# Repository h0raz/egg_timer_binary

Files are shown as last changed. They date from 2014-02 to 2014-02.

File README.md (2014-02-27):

egg_timer_binary
===================

My image

This is/will be a egg timer with a battery powered binary display

It shows either the minutes in 6 bits and the seconds or if time is greater than one hour the hour and the minutes and the seconds ticking

If the timer reaches zero it will beep until the rotary encoder is pressed

While the timer is not active you can change the timer by turning the encoder. Start/Pause, Reset is a Push on the encoder

If the seconds are not zero(eg you paused it) and you change the time the seconds will be set to 0

I set the OSCCAL so the drift is minimal and I don't need any crystal

As you can asume this project is still in development

The firmware is functional and finished for now but the layout needs some tweaking and I'm currently searching for a case which has the right size

> **Todo/Bugs:**
> 
> - Power down mode after a timeout
> - generalize Pin/Port settings
> - translate comments etc.
> - sound is a bit aweful
> - PCB desing
> - find case

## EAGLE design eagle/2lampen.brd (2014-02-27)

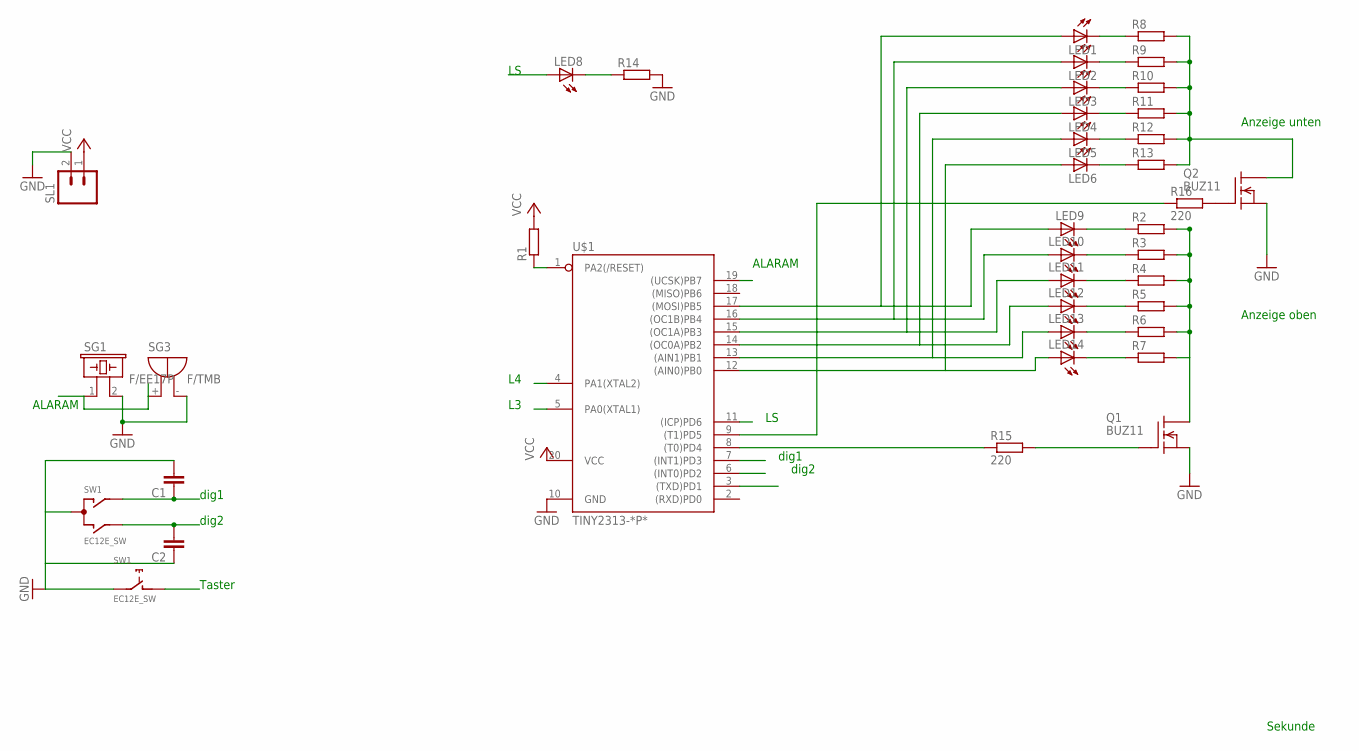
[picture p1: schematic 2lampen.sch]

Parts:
C1, C2: C-EU025-025X050; C025-025X050
LED1, LED2, LED3, LED4, LED5, LED6, LED9, LED10, LED11, LED12, LED13, LED14: LED5MM
LED8: LED3MM
Q1, Q2: BUZ11; TO220
R1, R13: R-EU_0204/7; 0204/7
R2, R3, R4, R5, R6, R7, R8, R9, R10, R11, R12, R14: R-EU_0204/2V; 0204V
R15, R16: 220; 0204V
SG1: F/EE17P
SG3: F/TMB
SL1: M02; 02P
SW1: EC12E_SW; ALPS_EC12E_SW
U$1: TINY2313-*P*; DIL20

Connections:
ALARM: SG1.1, SG3.+, U$1.19 ((UCSK)PB7)
DIG1: C1.1, SW1.A, U$1.7 ((INT1)PD3)
DIG2: C2.2, SW1.B, U$1.6 ((INT0)PD2)
GND: C1.2, C2.1, Q1.3 (S), Q2.3 (S), R14.2, SG1.2, SG3.-, SL1.2, SW1.C, SW1.E (2), U$1.10 (GND)
L1: LED1.A, LED9.A, U$1.17 ((MOSI)PB5)
L2: LED2.A, LED10.A, U$1.16 ((OC1B)PB4)
L3: LED3.A, LED11.A, U$1.5 (PA0(XTAL1)), U$1.15 ((OC1A)PB3)
L4: LED4.A, LED12.A, U$1.4 (PA1(XTAL2)), U$1.14 ((OC0A)PB2)
L5: LED5.A, LED13.A, U$1.13 ((AIN1)PB1)
L6: LED6.A, LED14.A, U$1.12 ((AIN0)PB0)
LS: LED8.A, U$1.11 ((ICP)PD6)
unnamed: LED6.K (C), R13.1
unnamed: LED5.K (C), R12.1
unnamed: LED4.K (C), R11.1
unnamed: LED3.K (C), R10.1
unnamed: Q1.2 (D), R2.2, R3.2, R4.2, R5.2, R6.2, R7.2
unnamed: LED2.K (C), R9.1
unnamed: LED1.K (C), R8.1
unnamed: LED8.K (C), R14.1
unnamed: LED9.K (C), R2.1
unnamed: LED10.K (C), R3.1
unnamed: LED11.K (C), R4.1
unnamed: LED12.K (C), R5.1
unnamed: LED13.K (C), R6.1
unnamed: LED14.K (C), R7.1
unnamed: Q2.2 (D), R8.2, R9.2, R10.2, R11.2, R12.2, R13.2
unnamed: Q1.1 (G), R15.2
unnamed: Q2.1 (G), R16.2
unnamed: R16.1, U$1.9 ((T1)PD5)
unnamed: R15.1, U$1.8 ((T0)PD4)
RESET: R1.1, U$1.1 (PA2(/RESET))
TAST: SW1.D (1)
VCC: R1.2, SL1.1, U$1.20 (VCC)

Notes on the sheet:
ALARAM
dig1
dig2
Taster
Anzeige oben
Anzeige unten
Sekunde

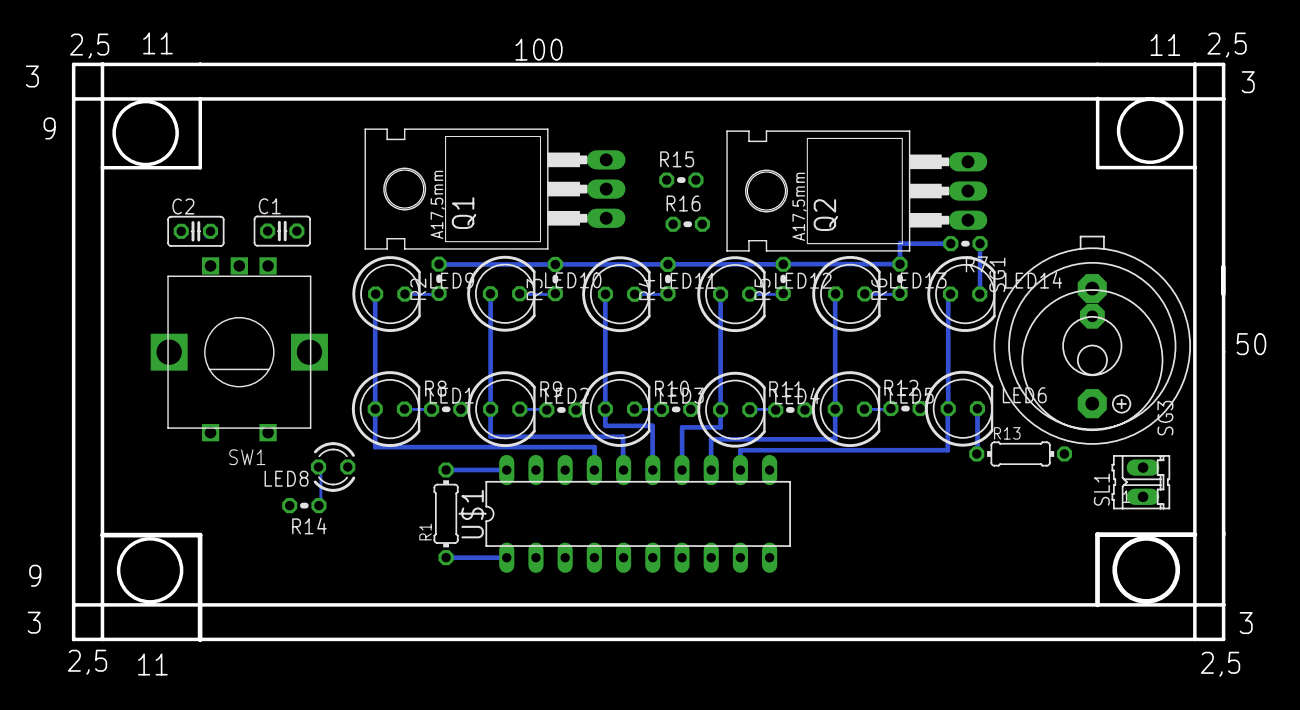
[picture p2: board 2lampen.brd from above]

Board: 2 copper layers, 100.0 x 50.0 mm, 38 parts (0 on the bottom side), 32 nets.

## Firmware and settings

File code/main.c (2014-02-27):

#include "main.h"

time_t *time = &gtime;

uint8_t timeshow(uint8_t ltime) {
    uint8_t show = 0;
    for(uint8_t i = 0; i <= 6; i++) {
        if (ltime & (1 << (5 - i))) {
            show |= (1 << i);
        }
    }
    return show;
}
void Zrpos() {
    if (time->s == 60) {
        time->s = 0;
        time->m++;
    }
    if (time->m == 60) {
        time->m = 0;
        time->h++;
    }
    if (time->h == 24) {
        time->h = 0;
    }
}

void Zrneg() {
    if (time->s == 255) {
        time->s = 59;
        time->m--;
    }
    if (time->m == 255) {
        time->m = 59;
        if (time->h > 0) {
            time->h--;
        }
    }
    if (time->h == 255) {
        time->h = 23;
        time->m = 59;
    }
}

void init(void) {
    //AUS/Eingänge festlegen
    TIMELEDDDR |= TIMELEDS;
    TIMESLEDDDR |= SLED;
    TIMELEDGNDDDR |= TIMELED1GND | TIMELED2GND;
    TASTERDDR &= ~(TASTER | DREH1 | DREH2);
    TIMELEDGNDP |= TIMELED1GND | TIMELED2GND;
    ALARMDDR|= ALARM1 | ALARM2;
    TASTERP |= DREH1 | DREH2 | TASTER;  //Taster auf aktive Low setzen

    OCR1AH = 244;       //Timer1_ Comp
    OCR1AL = 35;            //Timer1_ Comp  auf 62499 gestellt->Interrupt bei 62500; 8000000/62500/sekszori(128) ergibt 1s
    TCCR1B |= (1<<WGM12) | (1<<CS10);       //Timer1 auf CTC setzen und Timer1 prescaler setzten
    TCCR0B |= (1<<CS00);            //precaler für Timer0 auf /1 setzten
    TIMSK |= (1<<OCIE1A) | (1<<TOIE0);      //  Timer1 Init(Compare Match mode) und Timer0 Overflow Interrupt
    GIMSK |= (1<<PCIE);     //Global Interrupt Flag für PCINT setzen
    //PCMSK |= (1<<PCINT0) | (1<<PCINT1) | (1<<PCINT2);
    time->s = 0;        //Startzeit nach Init festlegen
    time->m = 5;
    time->h = 0;
    sekz = SEKZORI; //= (uint8_t)((1000000/1)/(OCR1H*256+OCR1L));
}

void statechange(uint8_t state) {
    if (state == AUS) {
        status = AUS;
        //leds off?
    }
    else if (state == CHO) {
        if (status == ALARM) {
            time->s = 0;
            time->m = 5;
            time->h = 0;
            sekz = SEKZORI;
            ALARMP &= ~(ALARM1|ALARM2);
        }
        status = CHO;
        TIMESLEDPORT &= ~SLED;
    }
    else if (state == RUN) {
        status = RUN;
    }
    else if (state == ALARM) {
        status = ALARM;
        sekz = SEKZORI/2;
        ALARMP |= ALARM1;
        ALARMP &= ~ALARM2;
        TIMESLEDPORT &= ~SLED;
    }
}

ISR (TIMER1_COMPA_vect) {
    comp();
}

void comp() {
    /*if (buttonstate == NLL) {
        count3 = (++count3) % (6);
        if (count3 == 0) {
            buttonstate = NONE;
            if ((PINB & TASTERP) == 0x00) {
                switch(status) {
                    case CHO: statechange(RUN); break;
                    case RUN: statechange(CHO); break;
                    case ALARM: statechange(CHO); break;
                }
            }
        }
    }*/
    count2 = (++count2) % sekz;
    if (status == ALARM && (count2 == ALARMDUTY)) {
        alarmstate = 1;
    }
    else if (count2 == 0) {
        alarmstate = 0;
    }

    if (status == RUN && count2 == 0) {
        time->s--;
        if (time->s == 0 && time->m == 0 && time->h == 0) {
            statechange(ALARM);
        }
        else {
            Zrneg();
        }
        if (time->h>0) {
            TIMESLEDPORT |=SLED;
        }
        else{
            TIMESLEDPORT &=~SLED;
        }
    }
    if (status==RUN && (count2==(sekz/2))) {
        TIMESLEDPORT &=~SLED;
    }

}

void buttoncheck(void) {
    uint8_t buttons = PINB & 0x07;
    if (button_state != BUT_LONG && button_state != BUT_SHORT) {
        if ((buttons & TASTER) != 0x04) {
            if (button_state != BUT_HOLD) {
                button_state = BUT_PRESSED;
                button_count++;
                if (button_count >= 800) {
                    button_state = BUT_LONG;
                }
            }
        }
        else{
            if (button_state == BUT_PRESSED && button_count >= 100) {
                button_state = BUT_SHORT;
            }
            else{
                button_state = BUT_NONE;
            }
        }
    }
    uint8_t zust = (buttons & 0x03);
    if (zust != zust_state) {
        if (zust == zust_new_state) {
            zust_count++;
        }
        else{
            zust_count = 0;
            zust_new_state = zust;
        }
        if (zust_count == 5) {
            zust_state=zust_new_state;

            if ((zust_state == DREH2) && dstate != 22) {
                dstate = 11;
            }
            else if ( zust_state == DREH1 && dstate != 12) {
                dstate = 21;
            }
            else if (dstate == 12 && zust_state == DREH1) {
                dstate = 13;
            }
            else if (dstate == 21 && zust_state == 0) {
                dstate = 22;
            }
            else if (dstate == 23 && zust_state == DREH12) {
                dstate = 24;
            }
            else if (dstate == 11 && zust_state == 0) {
                dstate = 12;
            }
            else if (dstate == 13 && zust_state == DREH12) {
                dstate = 14;
            }

            else if (dstate == 22 && zust_state == DREH2) {
                dstate = 23;
            }
            else{
                dstate=0;
            }
        }
    }
}


ISR(TIMER0_OVF_vect) {
    count++;
    if (count % 8 == 0) {
        buttoncheck();
    }
    if (count == 0)
        counterflag = NLL;
    if (count == SPWM_V)
        counterflag = L2;
    else if (count == 2 * SPWM_V - 1)
        counterflag = RES;
    if (count % ALARMFREQUENCY == 0 && alarmstate == 1) {
        ALARMP ^= ALARM1;
        ALARMP ^= ALARM2;
    }
}

int main(void) {
    init();
    statechange(CHO);
    sei();
    while(1)
    {

        if (button_state == BUT_LONG || button_state == BUT_SHORT) {
            button_state = BUT_HOLD;//or NONE so
            button_count = 0;
            switch(status) {
                case CHO: statechange(RUN); break;
                case RUN: statechange(CHO); break;
                case ALARM: statechange(CHO); break;
            }
        }
        /*else if (button_state == BUT_SHORT) {
            button_state = BUT_NONE;
            button_count = 0;
        }*/
        if (status == AUS) {
            set_sleep_mode(SLEEP_MODE_PWR_DOWN);
            sleep_mode();
            set_sleep_mode(SLEEP_MODE_IDLE);
        }
        else if (status == CHO) {
            if (dstate == 24) {
                dstate = 0;
                time->m++;
                time->s = 0;
                Zrpos();
            }
            else if (dstate == 14) {
                dstate = 0;
                if (time->m > 1 || time->h > 0) {
                    time->m--;
                    Zrneg();
                }
                time->s = 0;
            }
        }
        if (status == RUN || status == CHO) {
            if (counterflag == NLL) {
                counterflag = NONE;
                TIMELEDPORT = 0x00;
                TIMELEDGNDP &= ~TIMELED2GND;    //GND1 deaktivieren
                TIMELEDGNDP |= TIMELED1GND;     //GND2 aktivieren
                if (time->h > 0) {
                    TIMELEDPORT = timeshow(time->h);    //unten //Daten an PORT anlegen
                }
                else{
                    TIMELEDPORT = timeshow(time->m);
                }
            }
            else if (counterflag == L2) {
                counterflag = NONE;
                TIMELEDPORT = 0x00;
                TIMELEDGNDP |= TIMELED2GND;     //GND1 aktivieren
                TIMELEDGNDP &= ~TIMELED1GND;    //GND2 deaktivieren
                if (time->h > 0) {
                    TIMELEDPORT = timeshow(time->m);    //unten //Daten an PORT anlegen
                }
                else{
                    TIMELEDPORT = timeshow(time->s);
                }
            }
            else if (counterflag == RES) {
                counterflag = NONE;
                TIMELEDPORT &= ~TIMELEDS;
                TIMELEDGNDP &= ~(TIMELED1GND|TIMELED2GND);
            }
        }
        else if (status == ALARM) {
            if (alarmstate == 1) {
                if (counterflag == NLL || counterflag == L2) {
                    counterflag = NONE;
                    TIMELEDPORT |= TIMELEDS;
                    TIMELEDGNDP |= TIMELED1GND | TIMELED2GND;
                }
                else if (counterflag == RES) {
                    counterflag = NONE;
                    TIMELEDPORT &= ~TIMELEDS;
                    TIMELEDGNDP &= ~(TIMELED1GND | TIMELED2GND);
                }
            }
            else if (alarmstate == 0) {
                TIMELEDGNDP &= ~(TIMELED1GND | TIMELED2GND);
                TIMELEDPORT &= ~TIMELEDS;
            }
        }
        sleep_mode();
    }
    return 0;
}

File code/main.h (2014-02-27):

#include <avr/io.h>
#include <avr/interrupt.h>
#include <avr/sleep.h>
//#include <stdint.h>

#define status GPIOR0				//allgemeines Datenregister
#define counterflag GPIOR1			//allgemeines Datenregister
#define count GPIOR2				//allgemeines Datenregister
#define SPWM_V 60					//PWM Teiler max 128!
#define SEKZORI 128/2               //Zeitteiler für eine Sekunde

#define ALARMFREQUENCY 20 //from 1(~8kHz) to 254(~33Hz) 8~1kHz
#define ALARMDUTY 16 //from 0(on) to sekz/2 = 31(almost of)

//#define delz 12						//= (uint8_t)((1000000/1)/(OCR1H*256+OCR1L)*10);
									// = (F_CPU /Prescaler)/Comparematch oder so ;)
//Input/Output
#define TIMELEDDDR DDRD
#define TIMESLEDDDR DDRB
#define ALARMDDR DDRA
#define TASTERDDR DDRB
#define TIMELEDGNDDDR DDRB

//Ports
#define TIMELEDPORT PORTD
#define TIMESLEDPORT PORTB
#define ALARMP PORTA
#define TASTERP PORTB
#define TIMELEDGNDP PORTB

//PinNr
#define SLED (1 << 3)

#define TIMELEDS 0x3f
#define TIMELED1GND (1 << 6)	//unten
#define TIMELED2GND (1 << 5)	//oben


#define ALARM1 (1 << 0)
#define ALARM2 (1 << 1)
#define TASTER (1 << 2)
#define DREH1 (1 << 1)
#define DREH2 (1 << 0)
#define DREH12 (DREH1 | DREH2)

//globale variablen
volatile uint8_t dstate;
register uint8_t count2 asm("r2");
register uint8_t count3 asm("r3");
register uint8_t buttonstate asm("r4");
register uint8_t sekz asm("r5");
register uint8_t alarmstate asm("r6");


uint8_t zust_state;
uint8_t zust_new_state;
uint8_t zust_count;
uint8_t button_state;
uint16_t button_count;

typedef struct {
	uint8_t s;
	uint8_t m;
	uint8_t h;
	}time_t;

time_t gtime;

//enums
enum {AUS, CHO, RUN, ALARM};
enum {NONE, NLL, L2, RES};
enum{BUT_NONE, BUT_PRESSED, BUT_RELEASED, BUT_SHORT, BUT_LONG, BUT_HOLD};


//Funktionen
uint8_t timeshow(uint8_t ltime);
void Zrpos(void);
void Zrneg(void);
void init(void);
void comp(void);
void statechange(uint8_t state);

//Interrupts
ISR(TIMER0_OVF_vect);
ISR(TIMER1_COMPA_vect);
